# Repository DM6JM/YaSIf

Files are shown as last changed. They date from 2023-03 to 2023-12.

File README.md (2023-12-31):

# YaSIf

## Currently known issues
### Up to revision [v0.5.2 ](https://github.com/DM6JM/YaSIf/tree/v0.5.2)
- Wrong 3.3V LDO on TRX side used (U10). A TPS76333DBV is eqipped which can withstand only 10V. Magically it survives the 13.8V seen by external supplies. But this is no intended design.
  Possible alternatives:
  - TPS7A2433DBV (pin to pin compatible, about 5uA Iq and withstands 20V)
  - LDI559-3.3EN (pin to pin compatible, about 5uA Iq and withstands 18V)
  - TPS70933DBV (pin to pin compatible, about 2uA Iq and withstands 32V) 
- Leakage current on 13.8V at TRX. The circuit design always powers the 3.3V rail on the isolated TRX side of the PCB. The sum of the leakage currents in this revision is roughly 100uA which results in about 144mAh drainage of the internal battery in a period of 60 days. Not ciritical, but should be kept in mind.

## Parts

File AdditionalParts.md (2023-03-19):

#The additionally needed connectors
Some examples of connectors that can be used:
- Power connector to the radio: `50-00621` available at Digikey (839-1615-ND)
- 6pin mini-DIN to the radio: `MDP-006` available at Digikey (2057-MDP-006-ND)
- 8pin mini-DIN to the radio: `MDP-008` available at Digikey (2057-MDP-008-ND)

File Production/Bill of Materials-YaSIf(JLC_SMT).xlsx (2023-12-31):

Comment | Designator | Footprint | JLCPCBPartNum | Fitted
C4532X7R3A103K200KA | C1 | FP-C4532-200-0_4-IPC_B | C577346
CL10B104KC8NNNC | C2, C7, C12, C13, C19, C20, C21, C25, C26, C30, C31, C32 | FP-CL10-IPC_B | C15725
4.7uF 25V | C3, C6, C8, C9, C10, C11, C14, C15, C18, C24, C27, C28, C33 | CAPC1210(3225)220_M | C86052
CL10C470JC8NNNC | C4, C5, C16, C17, C23, C29 | FP-CL10-IPC_C | C1671
CC0603KRX7R9BB105 | C22 | FP-CC0603-DB-MFG | C559769
PRTR5V0U2X,215 | D2 | NXP-SOT143B-4_V | C12333
MBR0580S1-7 | D4 | FP-SOD123-MFG | C177047
BAT54C-7-F | D5 | FP-SOT23-IPC_B | C134405
0154004.DR | F1 | FP-0154-MFG | C206914
BLM41PG600SN1L | FB1, FB2 | FP-BLM41-0_2-IPC_B | C85844
1981568-1 | J1 | TECO-1981568-5_V | C428487
B2B-PH-SM4-TBT(LF)(SN) | J5 | FP-B2B-PH-SM4-TBT_LF_SN-MFG | C265003
BSS123-7-F | Q1 | FP-SOT23-IPC_C | C85107
27R | R1, R2, R7, R8, R21, R22, R24, R25 | J1-0603 | C192531
1k5 | R3, R9, R16, R17 | J1-0603 | C192164
330R | R4 | J1-0603 | C23138
10k | R5, R6, R12, R19, R20 | J1-0603 | C25804
1k | R10, R23 | J1-0603 | C21190
470R | R11 | J1-0603 | C25804
100R | R13, R26, R27, R28 | J1-0603 | C22775
TTC-5023 | T1, T3 | TRANSFORMER_TTC-5023 | C840532
FT230XS | u8 | FTDI-SSOP-16_L | C69082
CM108B | U1 | TQFP48 | C371347
TUSB2036VF | U2 | VF0032A_N | C43665
TPS2046BDR | U3 | D0008A_L
TPS76333DBVT | U4, U10 | DBV0005A_N | C7100
ISO7021D | U7 | FP-D0008A-IPC_B
LTV-815S | U9 | LTST-LTV-817S-4_V | C115455
DSC6101MI2B-048.0000 | Y1 | FP-C04-C04-1200-0 | C1671481

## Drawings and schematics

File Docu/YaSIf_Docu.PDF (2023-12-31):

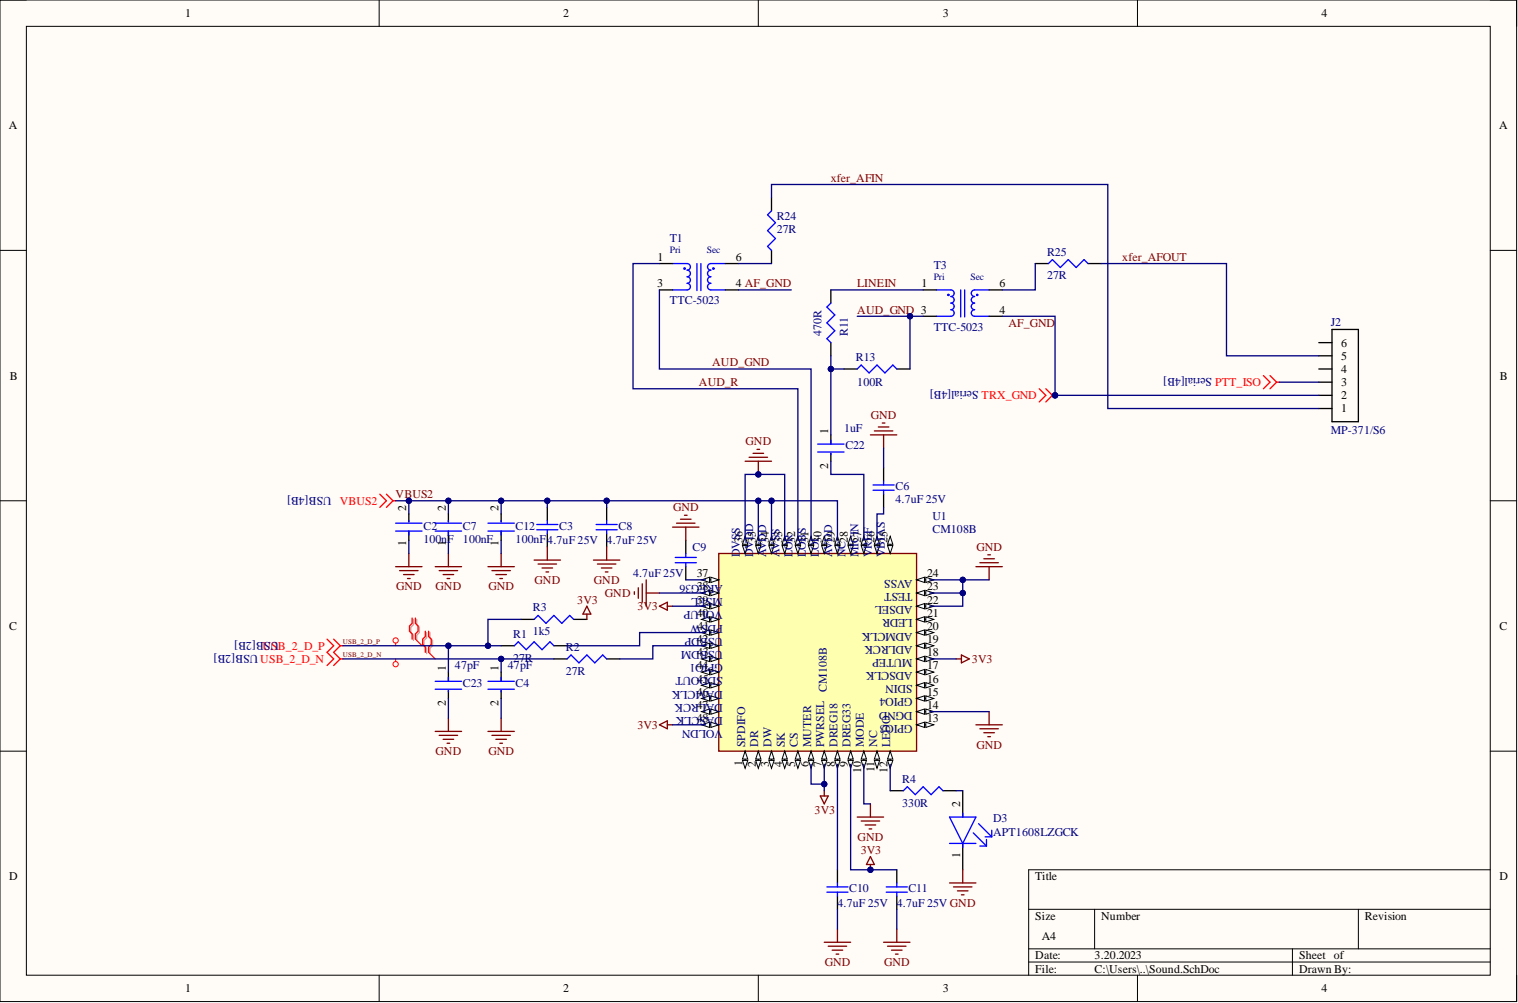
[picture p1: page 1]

3 | 4 AF_GND

GND

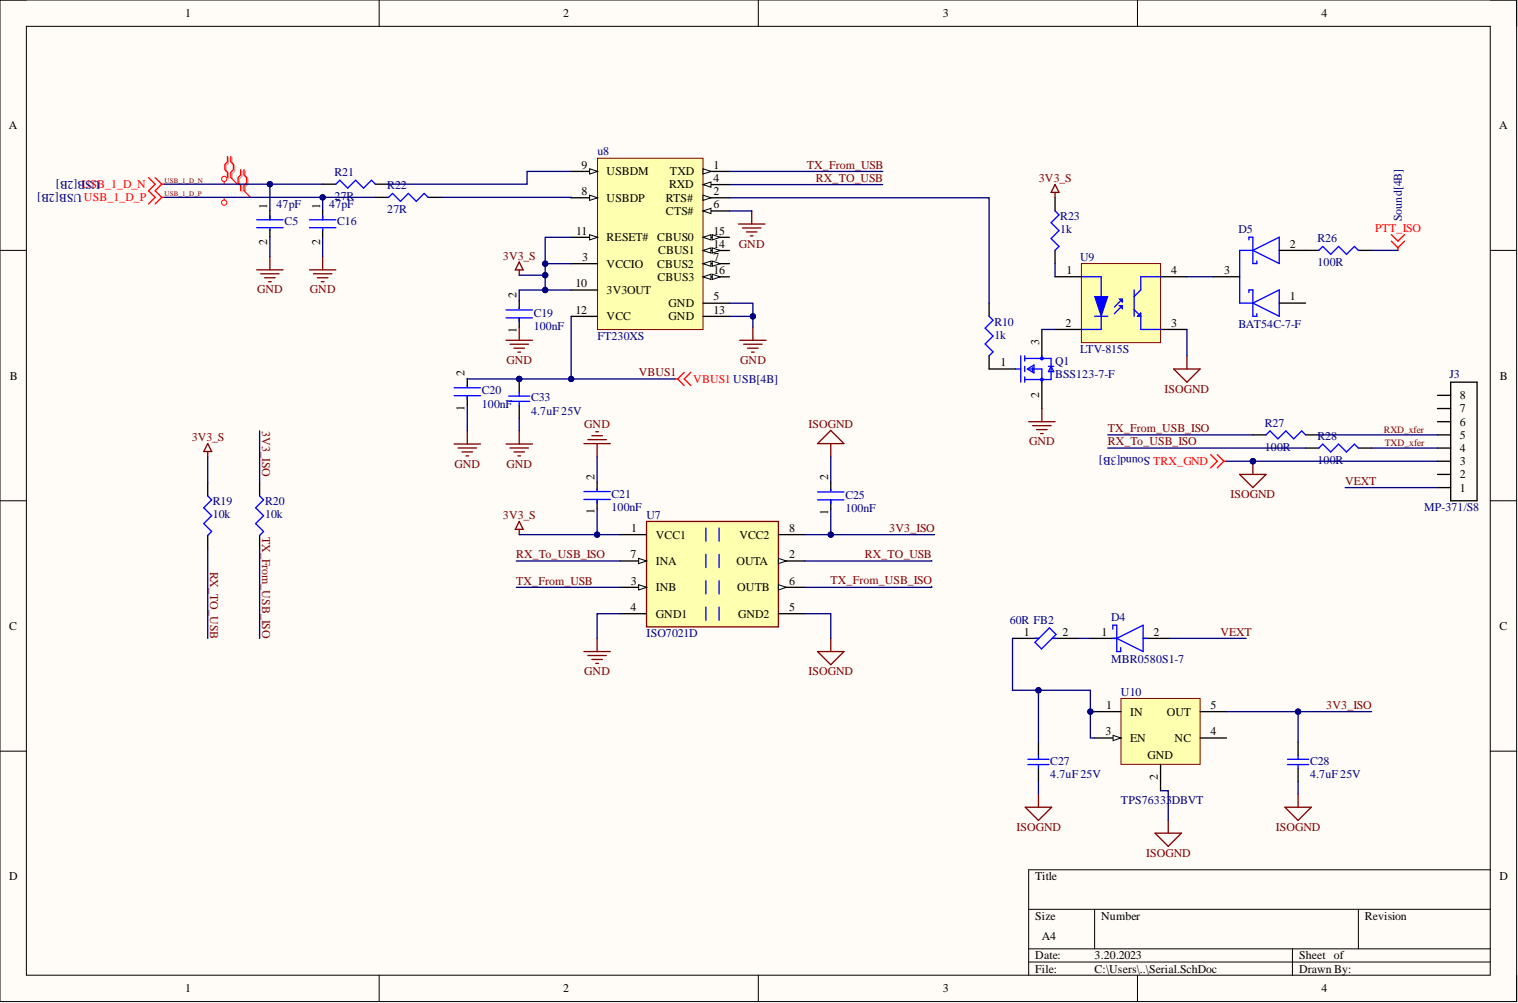
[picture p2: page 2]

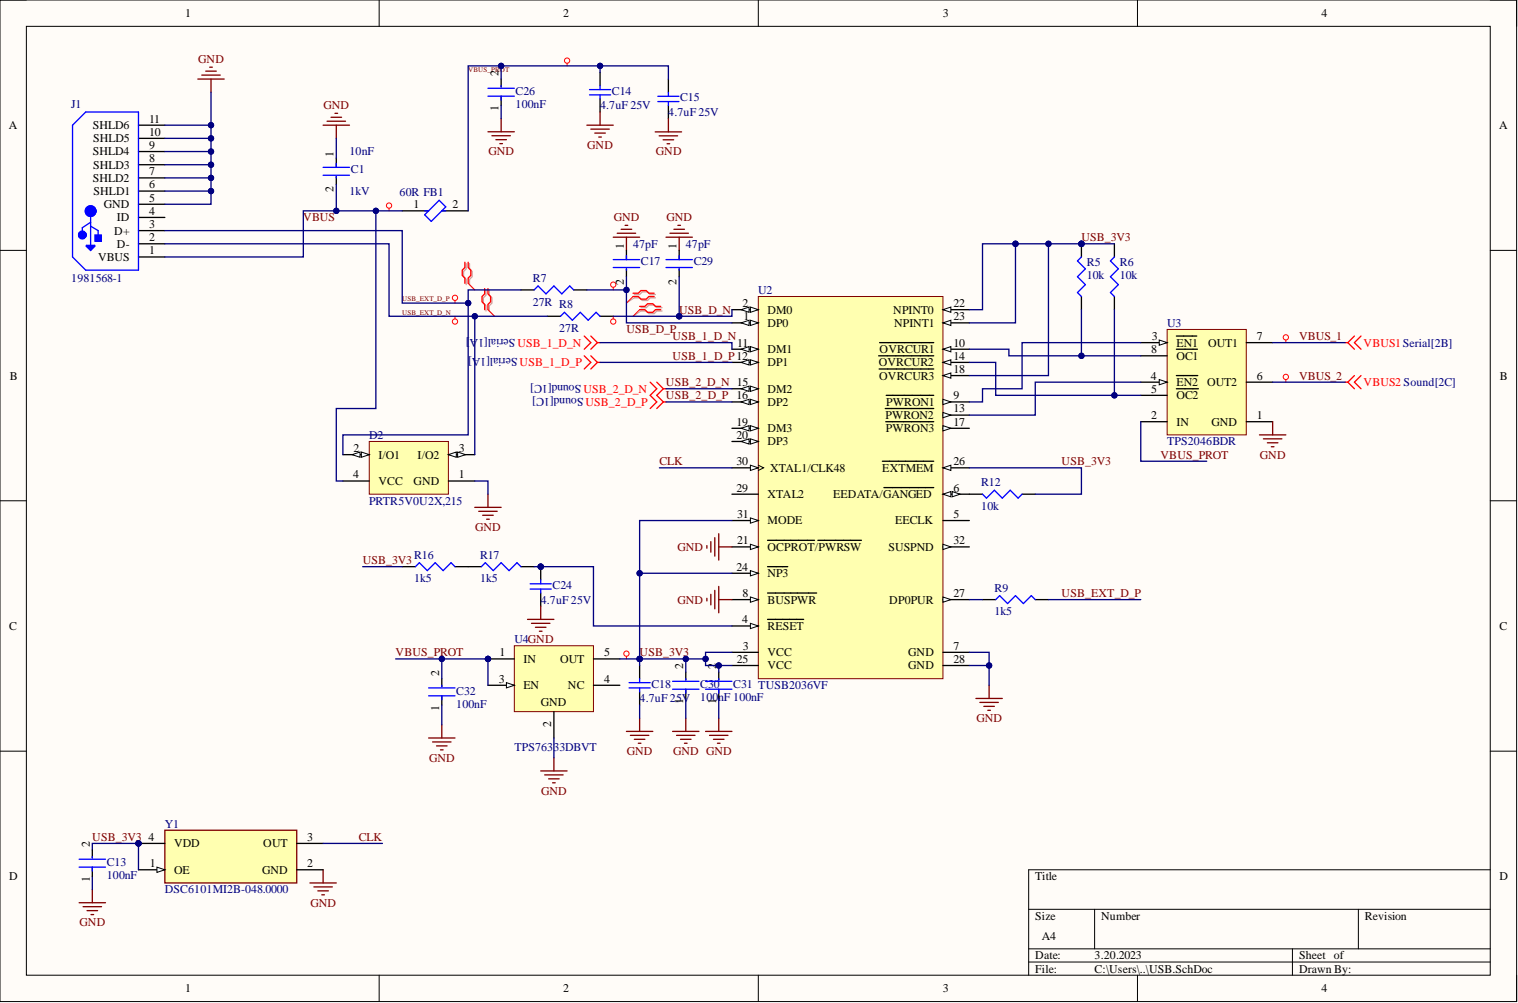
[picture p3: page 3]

OCPROT/PWRSW 21

BUSPWR 8

VCC 3 VCC 25

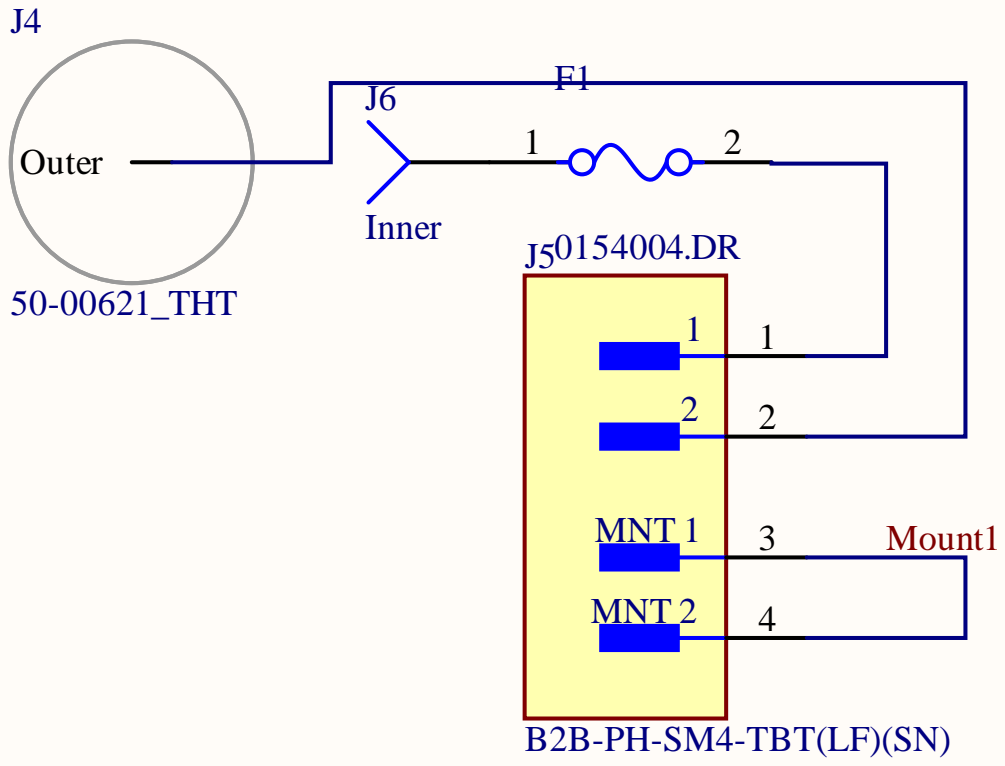
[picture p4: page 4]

B2B-PH-SM4-TBT(LF)(SN)

Comment | Designator | Footprint | JLCPCBPartNum | Fitted
C4532X7R3A103K200K A | C1 | FP-C4532-200-0_4-IPC_B | C577346
CL10B104KC8NNNC | C2, C7, C12, C13, C19, C20, C21, C25, C26, C30, C31, C32 | FP-CL10-IPC_B | C15725
4.7uF 25V | C3, C6, C8, C9, C10, C11, C14, C15, C18, C24, C27, C28, C33 | CAPC1210(3225)220_ M | C86052
CL10C470JC8NNNC | C4, C5, C16, C17, C23, C29 | FP-CL10-IPC_C | C1671
CC0603KRX7R9BB105 | C22 | FP-CC0603-DB-MFG | C559769
PRTR5V0U2X,215 | D2 | NXP-SOT143B-4_V | C12333
MBR0580S1-7 | D4 | FP-SOD123-MFG | C177047
BAT54C-7-F | D5 | FP-SOT23-IPC_B | C134405
0154004.DR | F1 | FP-0154-MFG | C206914
BLM41PG600SN1L | FB1, FB2 | FP-BLM41-0_2-IPC_B | C85844
1981568-1 | J1 | TECO-1981568-5_V | C428487
B2B-PH-SM4-TBT(LF)(SN) | J5 | FP-B2B-PH-SM4-TBT_LF_SN-MFG | C265003
BSS123-7-F | Q1 | FP-SOT23-IPC_C | C85107
27R | R1, R2, R7, R8, R21, R22, R24, R25 | J1-0603 | C192531
1k5 | R3, R9, R16, R17 | J1-0603 | C192164
330R | R4 | J1-0603 | C23138
10k | R5, R6, R12, R19, R20 | J1-0603 | C25804
1k | R10, R23 | J1-0603 | C21190
470R | R11 | J1-0603 | C25804
100R | R13, R26, R27, R28 | J1-0603 | C22775
TTC-5023 | T1, T3 | TRANSFORMER_TTC-5023 | C840532
FT230XS | u8 | FTDI-SSOP-16_L | C69082
CM108B | U1 | TQFP48 | C371347
TUSB2036VF | U2 | VF0032A_N | C43665
TPS2046BDR | U3 | D0008A_L
TPS76333DBVT | U4, U10 | DBV0005A_N | C7100
ISO7021D | U7 | FP-D0008A-IPC_B
LTV-815S | U9 | LTST-LTV-817S-4_V | C115455
DSC6101MI2B-048.0000 | Y1 | FP-C04-C04-1200-0 | C1671481

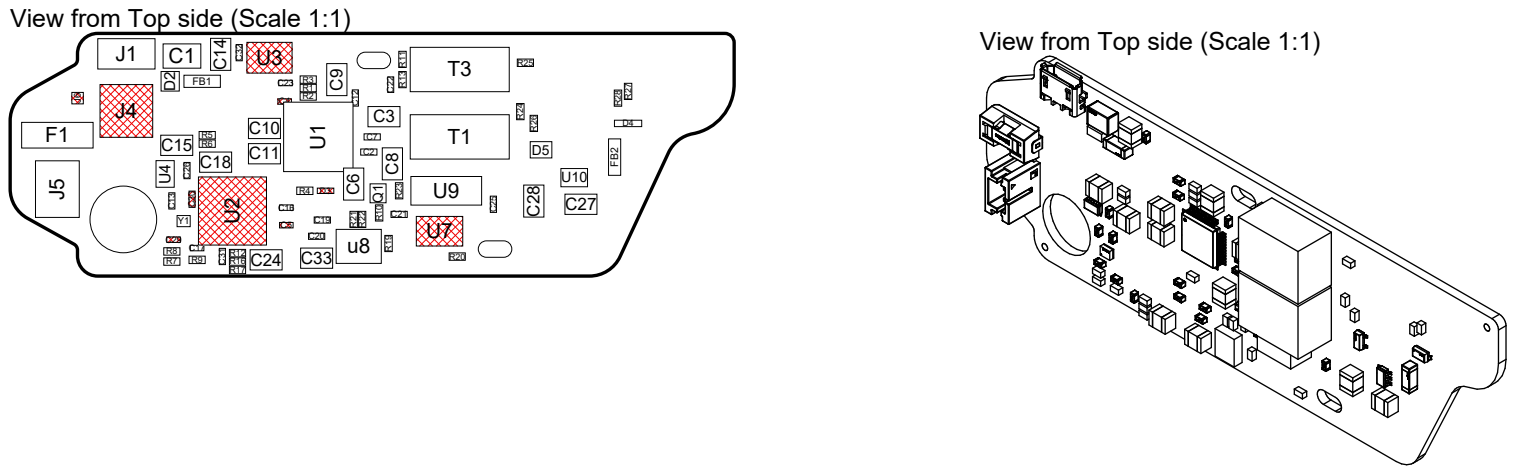
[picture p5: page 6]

View from Top side (Scale 1:1)

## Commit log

2023-01-18 Updated Params for suppliers Updated wrong designated C
    [PCB.PcbLib, PCB1.PcbLib, Serial.SchDoc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]
2023-01-29 Update: Added JLC Partnums Excluded certain ICs from assembly (temporarily)
    [Power.SchDoc, Serial.SchDoc, Sound.SchDoc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]
2023-02-01 Change: Now 4L Board to be able to have bottom layer copper-free for isolation purposes. Since no blind vias are supported, bottom vias have no copper attached to them. Together with solid solder mas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
    [Serial.SchDoc, Sound.SchDoc, USB.SchDoc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]
2023-02-17 Update: JLC PartNumber for LTV815S
    [PCB.PcbLib, PCB1.PcbLib, Serial.SchDoc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]
2023-02-20 Fix: Trace not covered by soldermask
2023-03-06 Change: Mic divider value lowered
    [Sound.SchDoc]
2023-03-20 Update: Working V1 Docu and production files
    [Bill of Materials-YaSIf(JLC_SMT).xlsx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]
2023-03-20 Update: Assembly data update
    [Serial.SchDoc, USB.SchDoc, YaSIf.PrjPcb]
2023-03-20 Update: Param update in PCB
